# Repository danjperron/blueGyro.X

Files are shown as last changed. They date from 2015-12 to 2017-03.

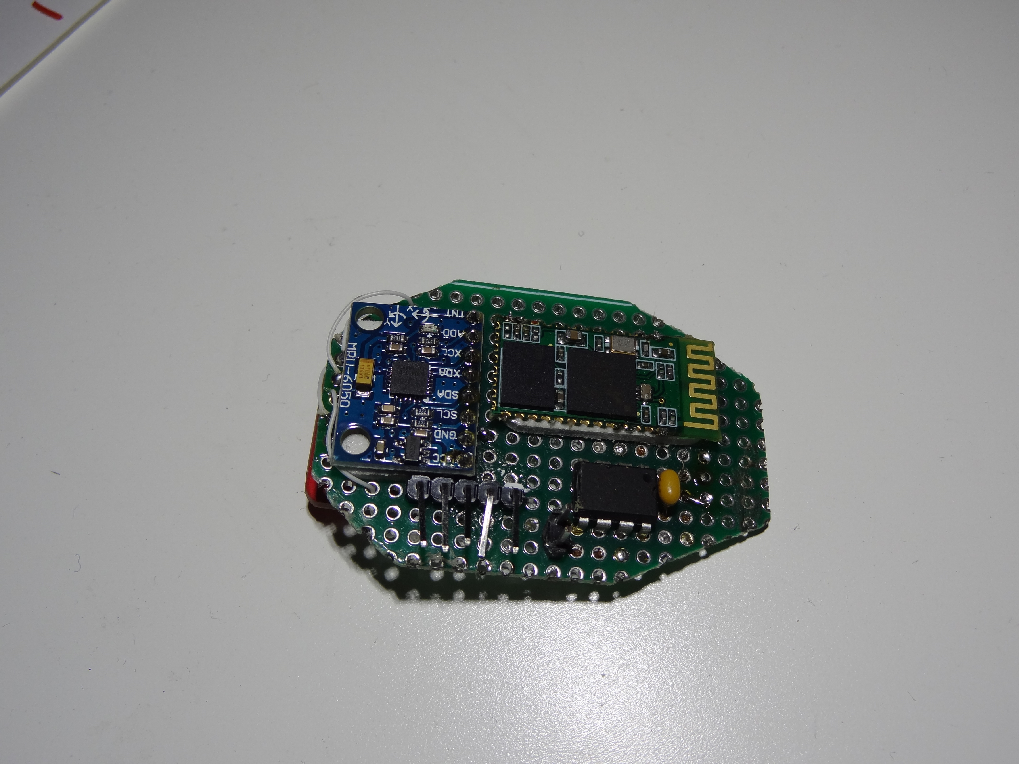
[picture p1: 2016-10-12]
DSC03212.JPG

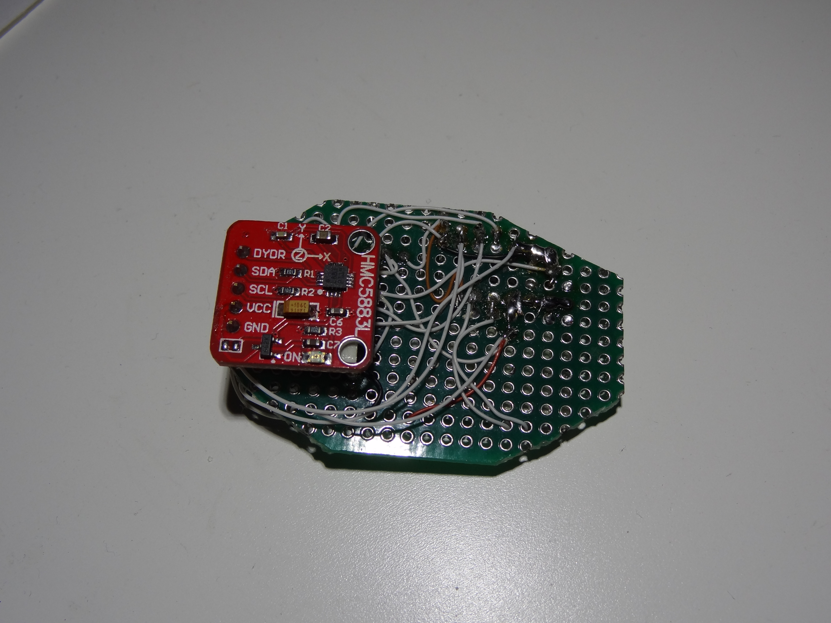
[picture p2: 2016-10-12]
DSC03213.JPG

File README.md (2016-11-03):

# blueGyro.X

Accéléromètre, gyroscope et magnétomètre dans un oeuf communicant avec bluetooth

Espérimentation pour vérifier la possibilité de lire la trajectoire de notre oeuf
avec des capteurs.

Le code principal utilise une puce Microchip pour lire le I2C des capteurs et de les envoyer
via bluetooth à un Raspberry Pi pour la captation des données.

Le répertoire 'catapult' contient l'information du lanceur utilisant un R/C servo et un digit
pour un count down.

Un vidéo sur youtube explique le fonctionnement du déclencheur de la catapulte.

https://www.youtube.com/watch?v=4Xm-DA170TM

D'autres vidéos et codes viendront 

V1.01 Ajout du magnétomètre.
V1.02 Ajout du la puce mémoire,La boîte noire. Le nouveau schéma est le fichier blueGyro_schema.png

N.B. il est possible de ne pas utiliser le magnétomètre et la boîte noire. Il sagit de faire un undefine.<br>
Pour le magnétomètre  ->  ajouter #undef HMC5883L_ENABLE  juste après le #define dans HMC5883L.h<br>
Pour le AT24CM02      ->  ajouter #undef AT24CM02_ENABLE juste après le #define dans AT24CM02.h

Les  commandes disponible sont,

    - [esc]  			IDLE MODE   Système en attente.
    - G , g ou [enter]  READY MODE  Système pret. Attend pour un signal d'accélération.
    - H  ou  h		    HIT MODE    Déclenchement de l'enregistrement. Simule une accélération soudaine.
    - I  ou i           INFO MODE   Affiche les données. Accéléromètre, gyroscope et magétomètre.
    - D  ou d           EEROM DUMP  Affiche en hexadécimal le contenue de la mémoire flash
    - ?                             Affiche la version.   (Idle mode seulement)
    - V or  v                       Affiche la tension de la batterie.  (Idle mode seulement)

-------

Accelerometer, gyroscope and magnetometer on bluetooth

V1.01 The HMC5883 magnetometer is added . If you don't want it, just rem #define HMC5883L_ENABLE in HMC5883L.h

catapultMag.jpg is the schematic.

-------
V1.02 Eerom memory I.C. add-on.  This allow to store data in case of bluetooth signal lost.

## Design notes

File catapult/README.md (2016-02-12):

## Le schéma.
platine_CatapultDeclencheur.jpg
>Le montage sur la platine.

Schema_CatapultDeclencheur.jpg
>Le schéma électrique.

catapultDeclencheur.fzz
>Fichier Fritzing

LTS-1720P.fzpz
>La composante LTS-1720P pour Fritzing.

LTS-1720.pdf
>La description du digit

## Le code python.</b><br>
catapult.py
>Le code principal

LED.py
>La classe LED

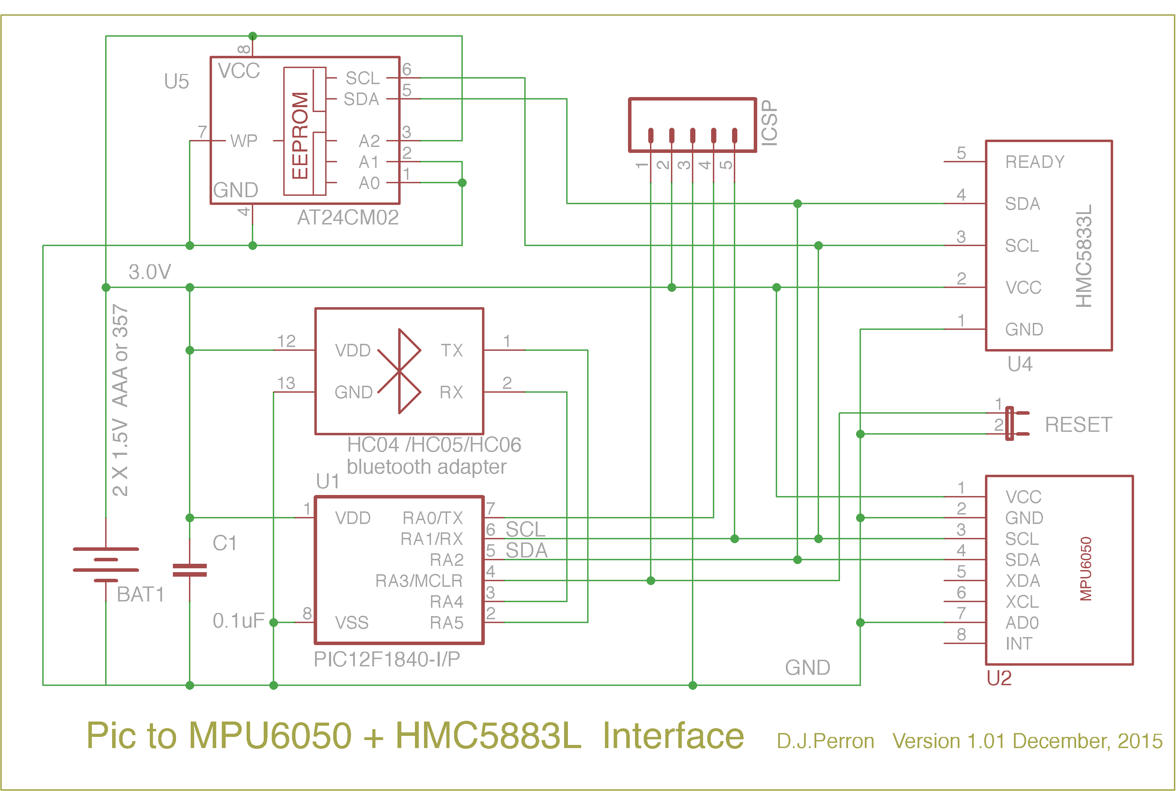
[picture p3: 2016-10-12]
blueGyro_schema.png

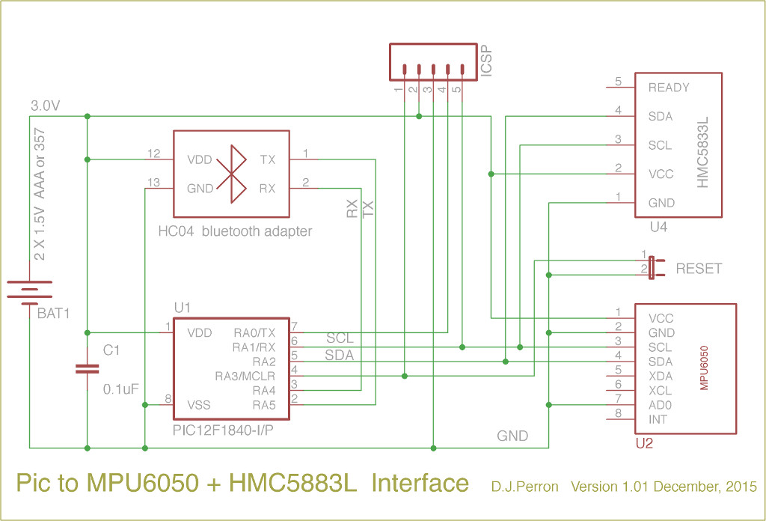
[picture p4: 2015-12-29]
catapultMag.jpg

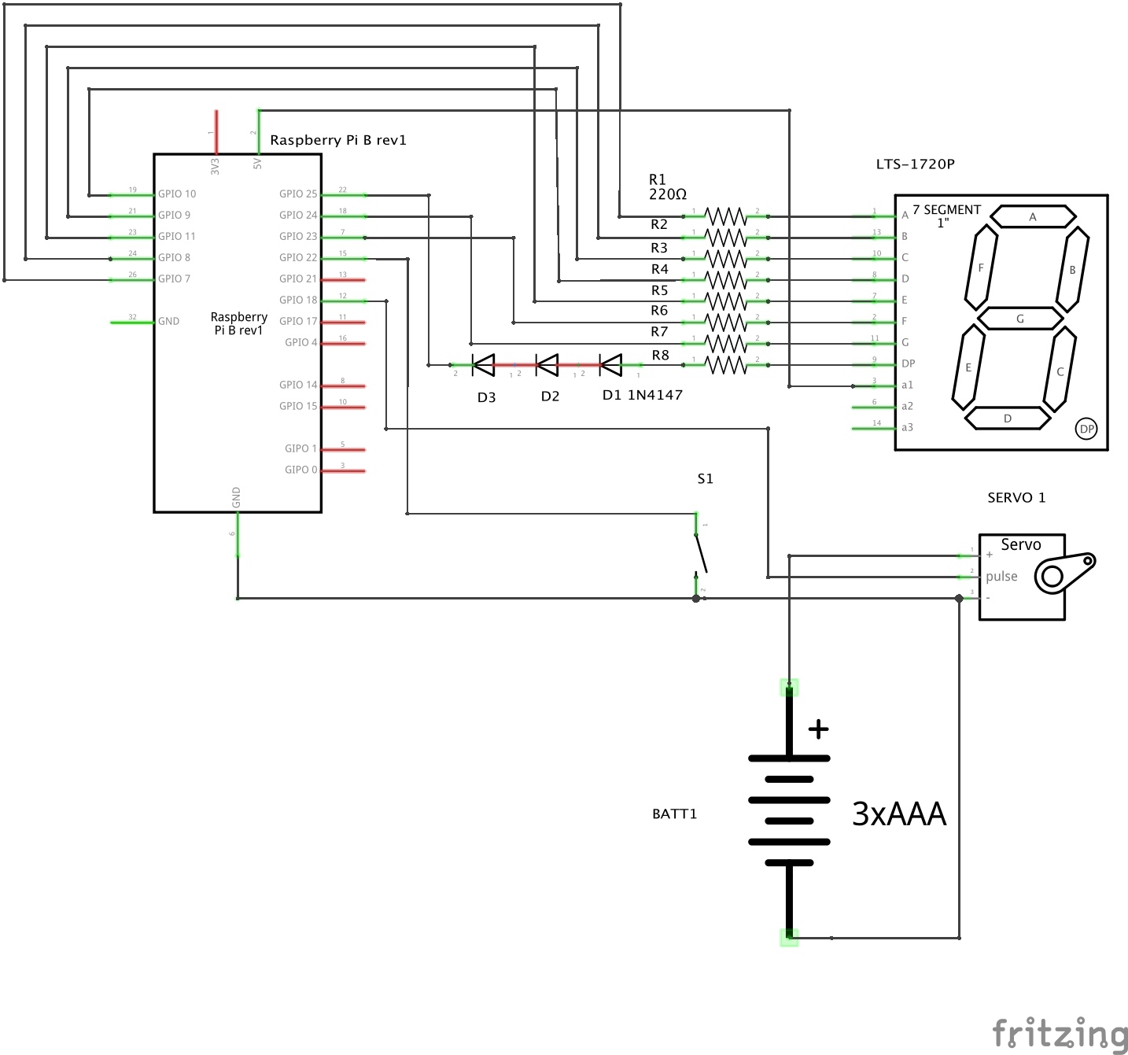
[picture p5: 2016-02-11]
catapult/Schema_CatapultDeclencheur.jpg

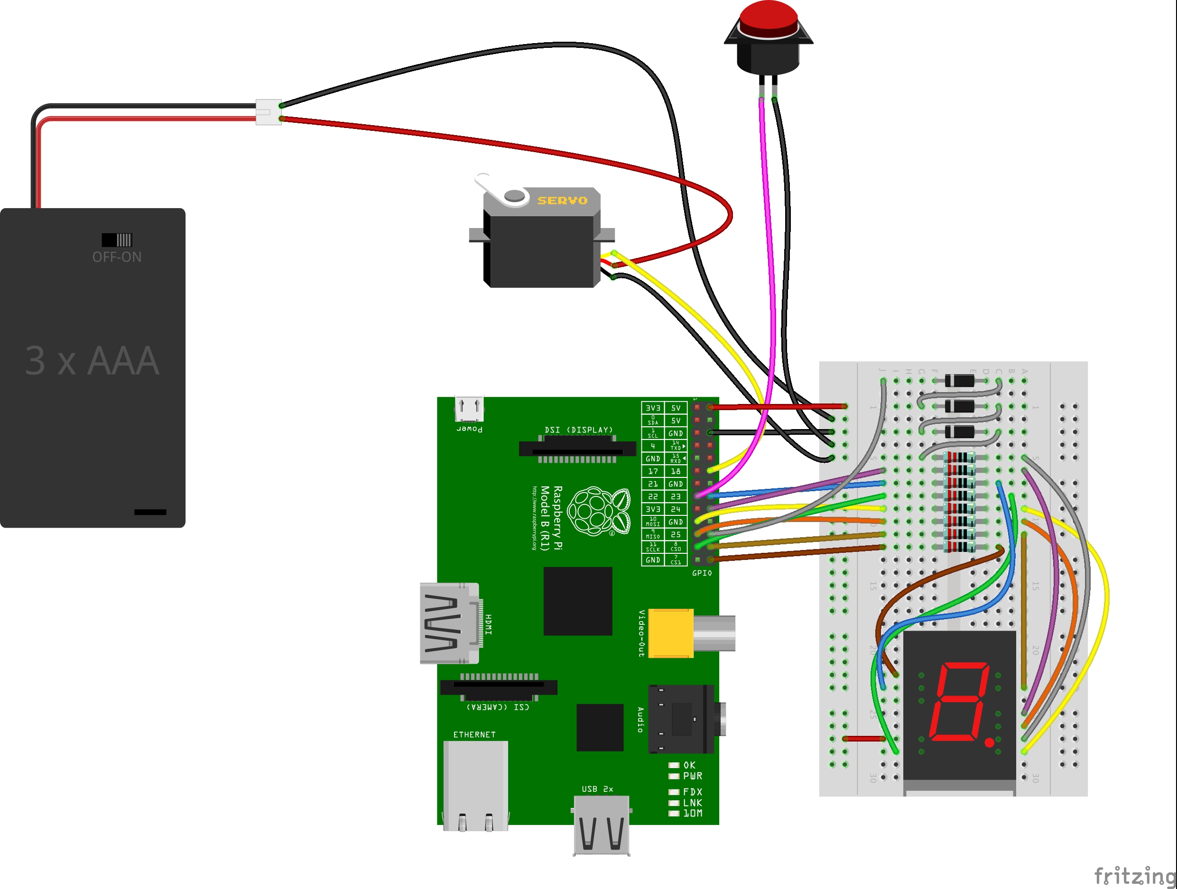
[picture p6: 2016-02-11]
catapult/platine_CatapultDeclencheur.jpg

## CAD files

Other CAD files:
dist/default/production/blueGyro.X.production.obj

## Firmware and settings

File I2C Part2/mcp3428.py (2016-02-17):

#!/usr/bin/python3

import io
import fcntl
import time

IOCTL_I2C_SLAVE = 0x0703


class i2c:

    def __init__(self, device, bus):

        self.fh = io.open("/dev/i2c-"+str(bus), "br+", buffering=0)

        # set device address

        fcntl.ioctl(self.fh, IOCTL_I2C_SLAVE, device)

    def write(self, values):
        self.fh.write(bytearray(values))

    def read(self, NumberOfByte):
        valueBytes = self.fh.read(NumberOfByte)
        return list(valueBytes)

    def close(self):
        self.fh.close()


class mcp3428:

    def __init__(self, I2CAddress, bus):
        self.I2CAddress = I2CAddress
        self.dev = i2c(I2CAddress, bus)

        self.CFG_STARTCONV = 0b10000000
        self.CFG_CHANNEL1 = 0b00000000
        self.CFG_CHANNEL2 = 0b00100000
        self.CFG_CHANNEL3 = 0b01000000
        self.CFG_CHANNEL4 = 0b01100000
        self.CFG_BITS12 = 0b00000000
        self.CFG_BITS14 = 0b00000100
        self.CFG_BITS16 = 0b00001000
        self.CFG_ONESHOT = 0b00000000
        self.CFG_CONTINOUS = 0b00010000
        self.CFG_GAIN1 = 0b00000000
        self.CFG_GAIN2 = 0b00000001
        self.CFG_GAIN4 = 0b00000010
        self.CFG_GAIN8 = 0b00000011

        self.channel = -1
        self.gain = 1
        self.bits = 16

    def __del__(self):
        self.dev.close()

    def startConversion(self, channel=1, gain=1, bits=16):
        # Ajuste Nomnbre de bits
        if bits == 12:
            control = self.CFG_BITS12
        elif bits == 14:
            control = self.CFG_BITS14
        else:
            # 16 bits par défaux
            bits = 16
            control = self.CFG_BITS16
        self.bits = bits

        control = control | self.CFG_ONESHOT

        # Ajuste le gain
        if gain == 8:
            control = control | self.CFG_GAIN8
        elif gain == 4:
            control = control | self.CFG_GAIN4
        elif gain == 2:
            control = control | self.CFG_GAIN2
        else:
            gain = 1
            control = control | self.CFG_GAIN1
        self.gain = gain

        # Selection du canal d'entrée
        if channel == 4:
            control = control | self.CFG_CHANNEL4
        elif channel == 3:
            control = control | self.CFG_CHANNEL3
        elif channel == 2:
            control = control | self.CFG_CHANNEL2
        else:
            channel = 1
            control = control | self.CFG_CHANNEL1

        # avons-nous un canal différent
        # si oui changeons le canal et attendons
        # pour stabiliser le condensateur interne

        if channel != self.channel:

            # Appliquer le nouveau canal+ config sans conversion
            self.dev.write([control])

            # attendons un peut
            time.sleep(0.001)

        self.channel = channel
        # Ok pret pour une conversion

        control = control | self.CFG_STARTCONV
        self.dev.write([control])

    def waitForConversion(self):
        # Attendons pour la fin de la conversion
        while True:
            time.sleep(0.001)
            info = self.dev.read(3)
            if (info[2] & 0x80) == 0:
                break

    def readValue(self):
        # ok conversion fait
        # Lecture de la conversion
        info = self.dev.read(2)
        UnsignedV = info[0] * 256 + info[1]

        # de valeur non signé à valeur signé
        if(UnsignedV > 32767):
            UnsignedV = UnsignedV - 65536

        # Ajustement de la ponderation au nombre de bits
        bitsFactor=1
        if self.bits == 12:
            bitsFactor = 16
        elif self.bits == 14:
            bitsFactor = 4

        # retour d la valeur en voltage
        return 2.048 / 32768.0 * UnsignedV / self.gain * bitsFactor

    def startReadValue(self, channel=1, gain=1, bits=16):
        self.startConversion(channel, gain, bits)

        # Attente initiale  dépendant du nombe de bits
        if bits == 12:
            time.sleep(1.0/328.0)
        elif bits == 14:
            time.sleep(1.0/82.0)
        else:
            time.sleep(1.0/20.5)

        # Vérification de la fin de la conversion
        self.waitForConversion()

        # retourne la valeur
        return self.readValue()

if __name__ == "__main__":

    a2d = mcp3428(0x68,0)

    for i in range(4):
        print("Channel {} value is {:.5f} Volt".format(i+1,a2d.startReadValue(i+1)))

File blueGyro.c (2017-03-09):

/////////////////////////////////////////////////////////////////////////////////////////////////////////////////////////
//  catapult
//
// Simple program to access MPU6050 accelerometer and report
// data via bluetooth using a HC04 serial to bluetooth adapter

//   Date: 26 Dec 2015
//   programmer: Daniel Perron
//   Version: 1.0
//   Processor: PIC12F1840
//   Software: MPLAB X IDE v3.15,  XC8 (v1.35) 

                   

///////////////////  How to program the IC.
//
//    1 - Use MPLAB with pickit 3  
//  or
//    2 - Use standalone pickit2 v 2.61 (Select the I.C. and load the corresponding hex file).
//  or
//    3 - Use Raspberry Pi board  with burnVLPx.py . Software available from https://github.com/danjperron/A2D_PIC_RPI 
//        

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
    You should have received a copy of the GNU General Public License
    along with this program.  If not, see <http://www.gnu.org/licenses/>.
*/



/*  COMMUNICATION PROTOCOL
    
      using TTL UART with fix baud at 115200, 8 bits data, no parity.
 
      ASCII COMMAND character
       [esc] 			-> IDLE  Go to idle mode (do nothing)
        G,g or enter	-> READY  Be ready for High G detection
        I or i          -> INFO   Display Acceleration info in G.
        H or h          -> HIT    Force High/Low G detection
        Z or z          -> Zero   Zero Gyro values (set offset)
       
        D or d          -> Dump   Dump flash data from AT24CM02
 

      Command available in IDLE mode only
        ?               -> display Release version.
        V or v          -> Display Battery Voltage.

        
       Record Format:   Everything in HEX Format (for speed, The PIC is too slow to decode decimal ascii)
               TTTTXXXXYYYYZZZZxxxxyyyyzzzz\r\n
        where TTTT is time in ms
              XXXX is acceleration on X axis (signed short integer)
              YYYY is acceleration on Y axis (signed short integer)
              ZZZZ is acceleration on Z axis (signed short integer)
              xxxx is gyro x
              yyyy is gyro y
              zzzz is gyro z


*/    
//////////////////////////  PORT DESCRIPTION
/*

 RA0    IN      not used 
 RA1	I/O    	I2C SCL
 RA2	I/O		I2C SDA
 RA3	IN		MCLR  Master Clear  (Reset cpu when is low)
 RA4	OUT	UART TX
 RA5	IN		UART RX
*/


// Dec 29 Magnetometer data add-on
// if you don't want magnetometer  undef HMC5883L_ENABLE in HMC5883L.h


// Oct 12 , 2016 Flash memory add-on
// Version 1.02



#include <htc.h>
#include <stddef.h>
#include <conio.h>
#include <stdlib.h>
#include "i2cMaster.h"
#include "MPU6050.h"
#include "AT24CM02.h"



#ifndef _XTAL_FREQ
 // Unless specified elsewhere, 4MHz system frequency is assumed
 #define _XTAL_FREQ 32000000
#endif




#ifdef __XC__
// CONFIG1
#pragma config FOSC = INTOSC // Oscillator Selection (INTOSC oscillator: I/O function on CLKIN pin)
#pragma config WDTE = OFF // Watchdog Timer Enable (WDT disabled)
#pragma config PWRTE = OFF // Power-up Timer Enable (PWRT disabled)
#pragma config MCLRE = ON // MCLR Pin Function Select (MCLR/VPP pin function is MCLR)
#pragma config CP = OFF // Flash Program Memory Code Protection (Program memory code protection is disabled)
#pragma config CPD = OFF // Data Memory Code Protection (Data memory code protection is disabled)
#pragma config BOREN = ON // Brown-out Reset Enable (Brown-out Reset enabled)
#pragma config CLKOUTEN = OFF // Clock Out Enable (CLKOUT function is disabled. I/O or oscillator function on the CLKOUT pin)
#pragma config IESO = OFF // Internal/External Switchover (Internal/External Switchover mode is enabled)
#pragma config FCMEN = ON // Fail-Safe Clock Monitor Enable (Fail-Safe Clock Monitor is enabled)

// CONFIG2
#pragma config WRT = OFF // Flash Memory Self-Write Protection (Write protection off)
#pragma config PLLEN = OFF // PLL Enable (4x PLL enabled)
#pragma config STVREN = ON // Stack Overflow/Underflow Reset Enable (Stack Overflow or Underflow will cause a Reset)
#pragma config BORV = LO // Brown-out Reset Voltage Selection (Brown-out Reset Voltage (Vbor), low trip point selected.)
#pragma config LVP = ON // Low-Voltage Programming Enable (Low-voltage programming enabled)

#else

__CONFIG(FOSC_INTOSC & WDTE_OFF & PWRTE_OFF & MCLRE_ON & BOREN_OFF & CP_OFF & CPD_OFF & CLKOUTEN_OFF & IESO_OFF & FCMEN_OFF);
__CONFIG(WRT_OFF & PLLEN_OFF & BORV_LO & LVP_ON);
__IDLOC(0000);




#ifndef BORV_LO
#define BORV_LO BORV_19
#endif


#endif

// store/read gyro offset into flash memory

//Set default value
__EEPROM_DATA(0,0,0,0,0,0,0,0);

typedef struct{
  short GyroX,GyroY,GyroZ;
}settingsStruct;


settingsStruct Setting;

#define iabs(A)  (A<0 ?  (-A) :  A)

 near volatile unsigned short Timerms;       //  Interrupt Timer counter in ms 
 volatile unsigned short TimerCrash;   // Interrupt Timer counter in ms  

 
 
 // variable for Gyro offset calculation
 long  AccGyroX;
 long  AccGyroY;
 long  AccGyroZ;
 short AccGyroCount;
 
 //unsigned short Timerms;       //  Interrupt Timer counter in ms 
 //unsigned short TimerCrash;   // Interrupt Timer counter in ms  

 
// MODE OF OPERATION
//  
//  IDLE  => Do nothing
//  INFO  => Display every second the MPU6050 Data
//  READY => Wait until the unit  get more than 1.5G 
//  HIT   => Output data no matter what
 

#define MODE_IDLE      			0
#define MODE_READY  	      	1
#define MODE_HIT			 	3
#define MODE_GYRO_OFFSET        4
#define MODE_DUMP               5
#define MODE_INFO				100

volatile unsigned char Mode= 0xff;
volatile unsigned char NewMode = MODE_IDLE;

// serial buffer 
#define SERIAL_BUFFER_SIZE 32
volatile unsigned char InFiFo, OutFiFo;   // these are the buffer pointers for interrupt serial communication; InFiFo ctrl by putch, OutFiFo ctrl by interrupt
char SerialBuffer[SERIAL_BUFFER_SIZE];


// eerom function
// EEPROM LOAD AND SAVE SETTING
void LoadSetting(void)
{
  unsigned char  idx;
  unsigned char  * pointer = (unsigned char *) &Setting;

  for(idx=0; idx < sizeof(Setting);idx++)
     *(pointer++) = eeprom_read(idx);
}

void SaveSetting(void)
{
  unsigned char  idx;
  unsigned char  * pointer = (unsigned char *) &Setting;
 
  for(idx=0; idx < sizeof(Setting);idx++)
      eeprom_write(idx, *(pointer++));
}


short GetGyroWithOffset(short value, short Goffset)
{
    short _temp;
    
    if(value > 0)
    {
      if(Goffset <0)
      {
          _temp = 32767 +Goffset;
          if(value >= _temp)
              return 32767;
      }
    }   
    else 
    {
    if(Goffset >0)
    {
        _temp = -32768 + Goffset;
        if(value <= _temp)
            return -32768;
    }
    }
      return(value - Goffset);
}



void Init1msTimer()   
{

// we want 1mss period so
// base osc= 32Mhz   clock= 32Mhz/4 
// clock of 8Mhz = 125ns   1ms / 125ns = 8000
// 8000  prescaler of 64 = 125 start count
T2CON=0;
 PR2 = 125; 
TMR2=0;
T2CON= 0b00000111; // Timer on prescaller 64
 // Enable IRQ
TMR2IF=0;
Timerms=0;
TMR2IE=1;
PEIE = 1;
GIE=1;
}




void CalculateSumOfSquare(void);
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

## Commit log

2015-12-29 Add HMC5883L device
    [blueGyro.X.production.obj]
2016-02-11 add schema
    [catapultDeclencheur.fzz]
2016-10-12 add magnetometer
    [blueGyro.X.production.obj]
2016-10-12 Add eerom
    [blueGyro.X.production.obj]
2017-03-09 ADD hexfile for MPU6050 only NO magnetometer and NO eerom

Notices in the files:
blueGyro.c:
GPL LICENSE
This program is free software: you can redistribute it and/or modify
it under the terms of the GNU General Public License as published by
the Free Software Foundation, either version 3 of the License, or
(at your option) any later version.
